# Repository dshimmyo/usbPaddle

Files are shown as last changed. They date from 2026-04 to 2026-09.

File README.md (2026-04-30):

I'm pretty nostalgic about old game consoles like the Atari 2600, and for years I've been wondering why I can't play games like Breakout or Kaboom! or Warlords with a proper paddle controller, so I set out to find out what I can do about it.
This project is the beginning of that adventure.
Basically, this is some arduino code that I installed into an Adafruit Keeboar 2040 which is based on and RP2040. Some time in the near future I'll build a more generic version using the RP2040.
Anyway, the gist of it is, you'll need a 10K potentiometer with ground on one outer lug and 3.3vdc on the other outer lug. The wiper is wired to one of the analog input pins on the kb2040.
The analog signal you get from the potentiometer is your paddle rotation. It's all in the code.
The reason this script is so huge is because I had to experiment with a bunch of modes to see what works where. But basically, just use the default mode.
Unfortunately it only works on basically on or two devices using one specific OS. I got it working on an Anbernic RG350xxH and RG40xxH running MuOS Banana.
For some reason, using that specific OS and whatever version of retroarch they use, it works great with the paddle. Every other software, OS compbination I've tried maps the paddle as if it's a joystick so it control velocity which is wrong.
The paddle is supposed to map directly to the position of the paddle.

Anyway, this would make more sense in a video and I'll post a schematic of my circuit soon.

Oh I forgot to mention I had to add a bunch of buttons to this paddle because when I switch to this device in retroarch I can't use the buttons on the anbernic so I needed a way to navigate out of the retroarch menus to play the game, thus all the dang buttons.



In this image I'm running a gametank game using the GameTankEmulator which has native support for my paddle because I programmed it that way ;)

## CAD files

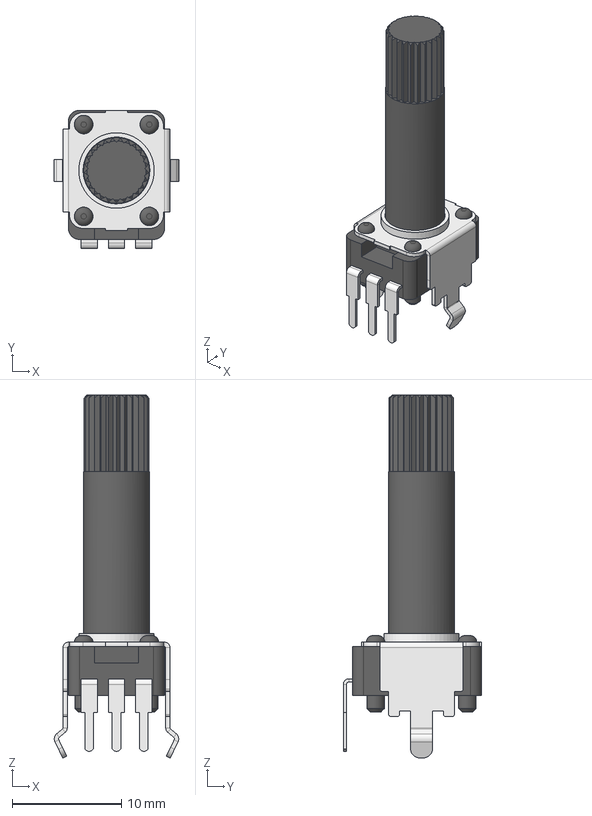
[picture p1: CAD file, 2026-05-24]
usbPaddleKicad/ALPS-RK09K_color.fcstd
11.4 x 12.6 x 33.2 mm
pin1
pin3
pin2

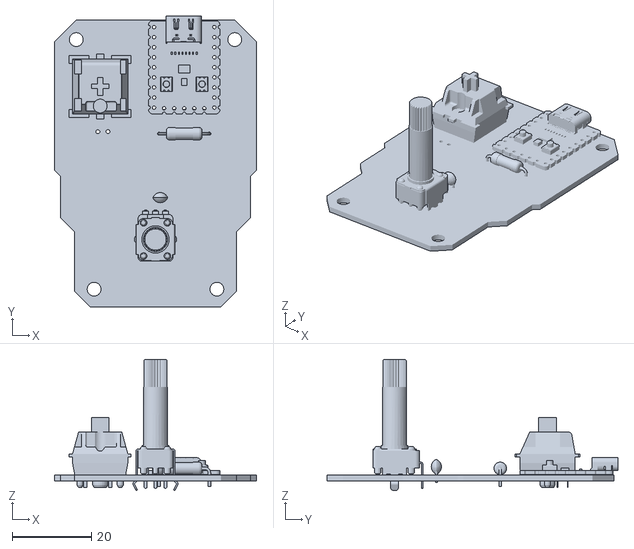
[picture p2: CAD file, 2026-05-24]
usbPaddleSingleKicad/paddleBaseStation.stl
51.0 x 73.4 x 33.2

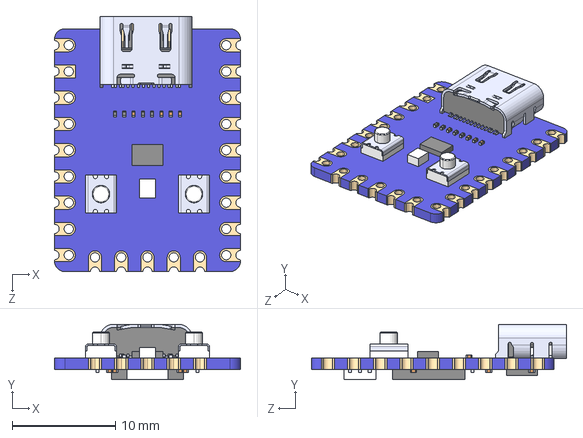
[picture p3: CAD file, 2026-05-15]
usbPaddleSingleKicad/RP2040-ZERO/RP2040-ZERO.step
18.0 x 5.35 x 24.7 mm

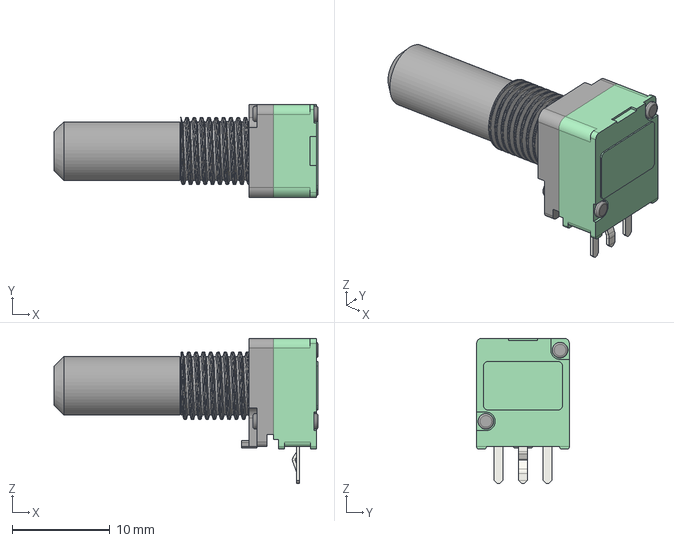
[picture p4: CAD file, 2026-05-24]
usbPaddleKicad/ALPS-RK097.step
27.1 x 9.50 x 14.9 mm

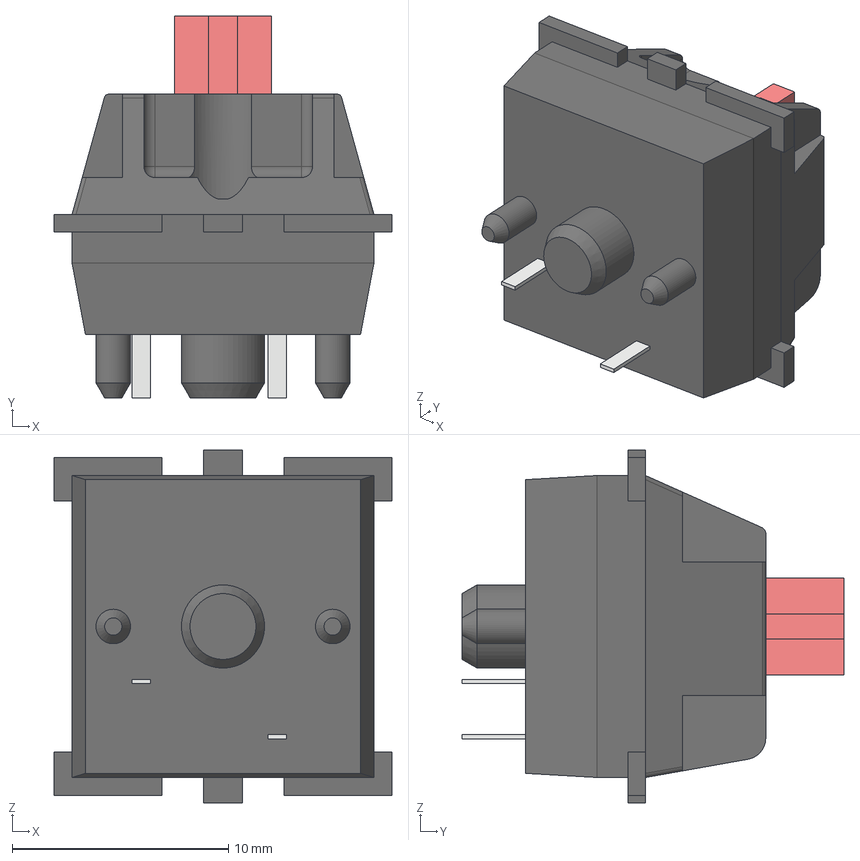
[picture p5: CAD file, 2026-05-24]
usbPaddleKicad/switch.step
15.6 x 17.7 x 16.3 mm

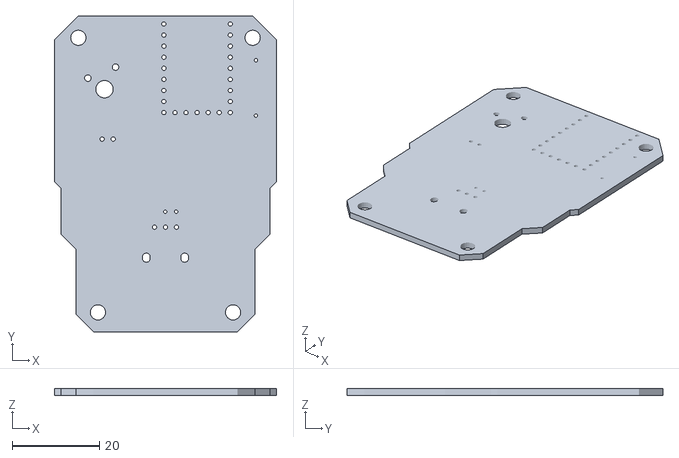
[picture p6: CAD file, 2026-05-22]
usbPaddleSingleKicad/paddleSingle.stl
51.0 x 72.5 x 1.51

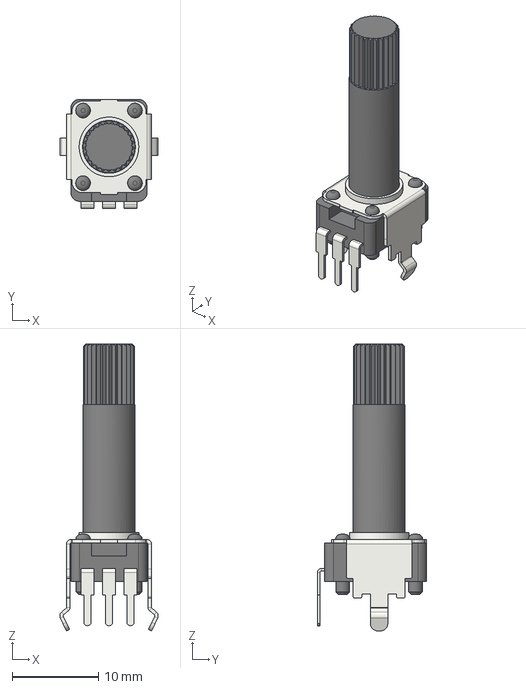
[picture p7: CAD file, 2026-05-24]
usbPaddleKicad/ALPS-RK09K.step
11.4 x 12.7 x 33.2 mm

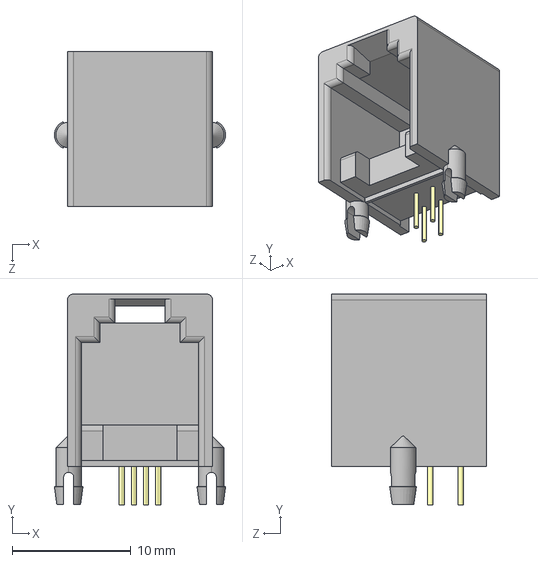
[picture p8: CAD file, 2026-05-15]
usbPaddleSingleKicad/GLX-N-64M--3DModel-STEP-484052.STEP
14.4 x 17.8 x 13.0 mm

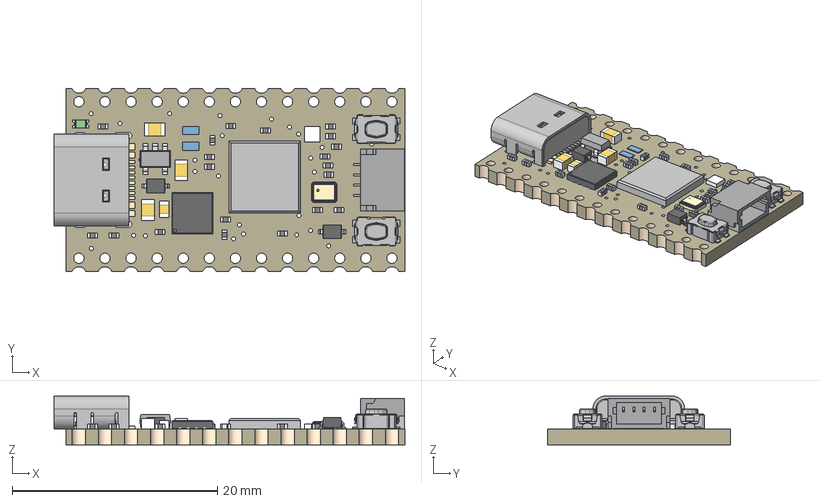
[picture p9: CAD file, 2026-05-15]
usbPaddleSingleKicad/5302 KB2040.step
34.2 x 17.8 x 4.77 mm
Board
10µF x 2
AP2112K-3.3
KMR2 x 2
10K x 20
WS2812B_SK6805_1515
NSR0320 x 2
8MB QSPI Flash
1uF x 2
RP2040_QFN56
12MHZ
1uF_1
USB TYPE C
FUSE
STEMMA_I2C_QTSKINNY
GREEN

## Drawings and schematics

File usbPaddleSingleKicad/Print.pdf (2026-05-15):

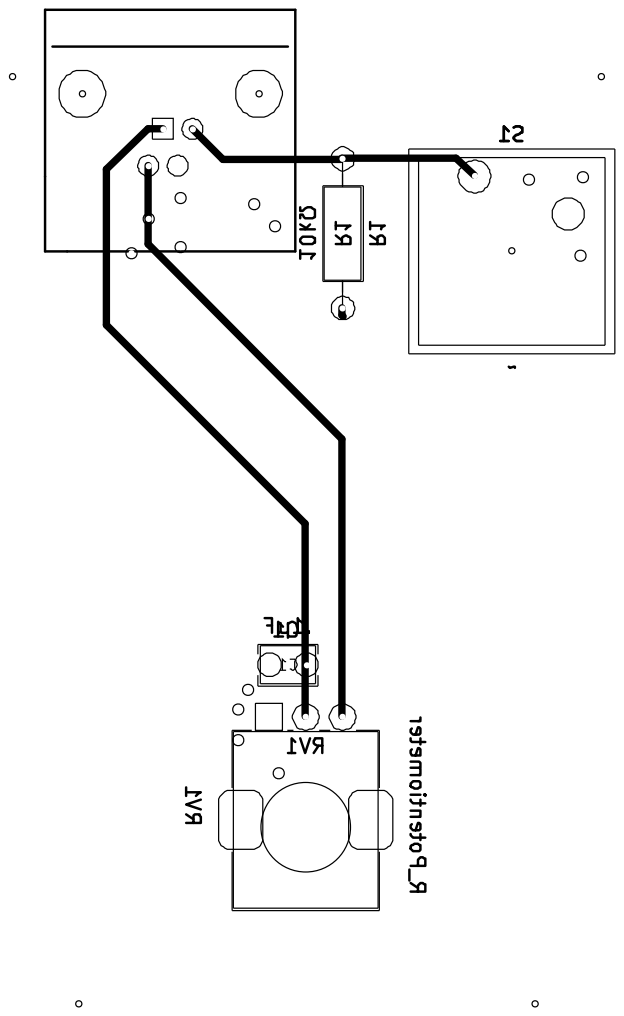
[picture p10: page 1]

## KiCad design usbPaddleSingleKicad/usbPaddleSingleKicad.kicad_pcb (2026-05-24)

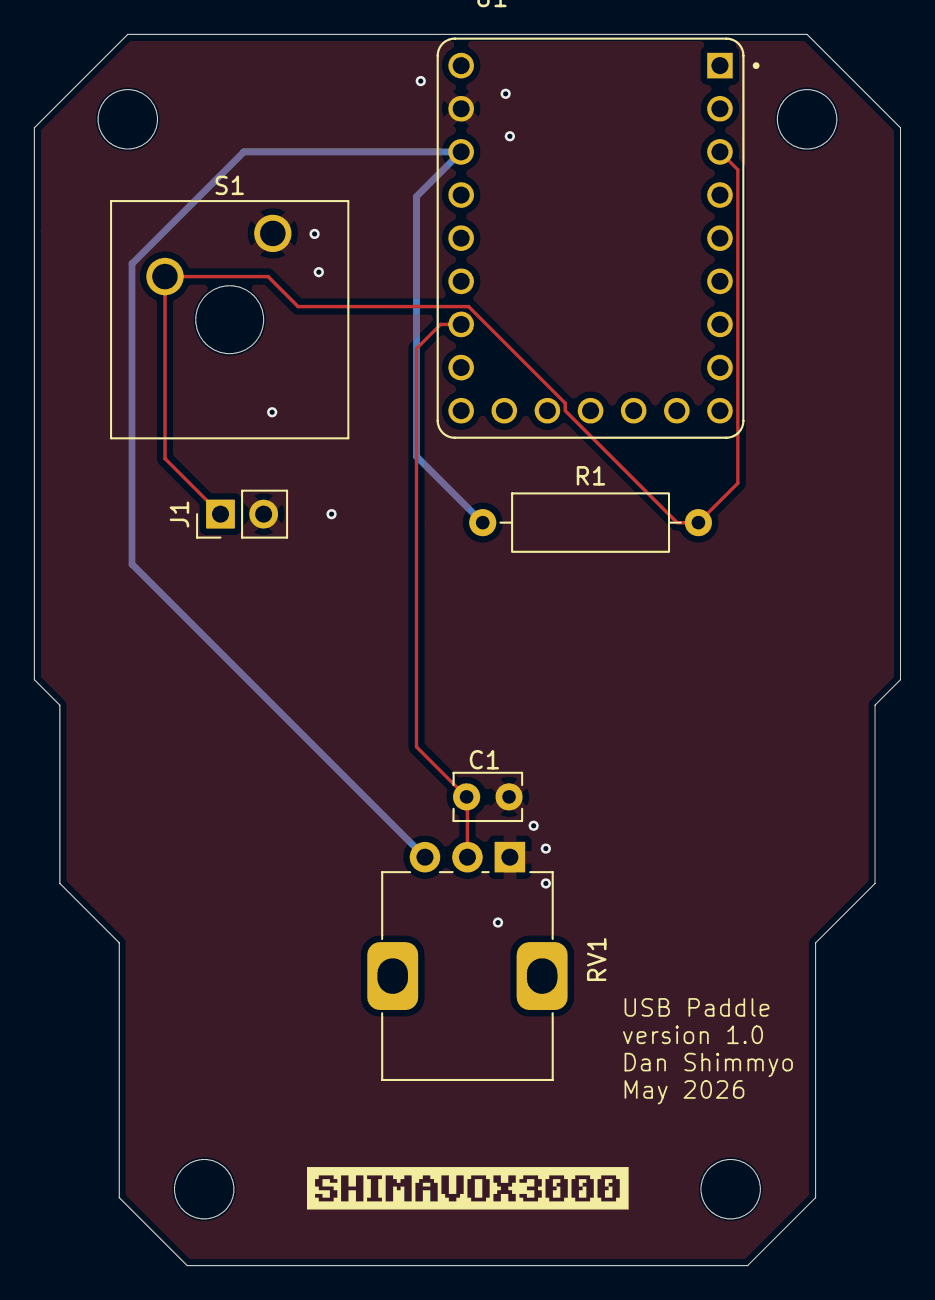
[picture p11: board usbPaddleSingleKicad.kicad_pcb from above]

Board: 2 copper layers, 51.0 x 72.5 mm, 6 parts (0 on the bottom side), 4 nets.

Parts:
C1: .1µF; C_Disc_D3.8mm_W2.6mm_P2.50mm
J1: Conn_01x02_Pin; PinHeader_1x02_P2.54mm_Vertical
R1: 10kΩ; R_Axial_DIN0309_L9.0mm_D3.2mm_P12.70mm_Horizontal
RV1: R_Potentiometer; Potentiometer_Alps_RK09K_Single_Vertical
S1: SW_Cherry_MX_1.00u_Plate
U1: RP2040-ZERO; MODULE_RP2040-ZERO

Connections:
GND: C1.1, J1.2, RV1.1, S1.1, U1.22 (GND)
unnamed: J1.1, R1.2, S1.2, U1.3 (GP2)
unnamed: C1.2, RV1.2, U1.17 (GP26)
VCC: R1.1, RV1.3, U1.21 (3V3)

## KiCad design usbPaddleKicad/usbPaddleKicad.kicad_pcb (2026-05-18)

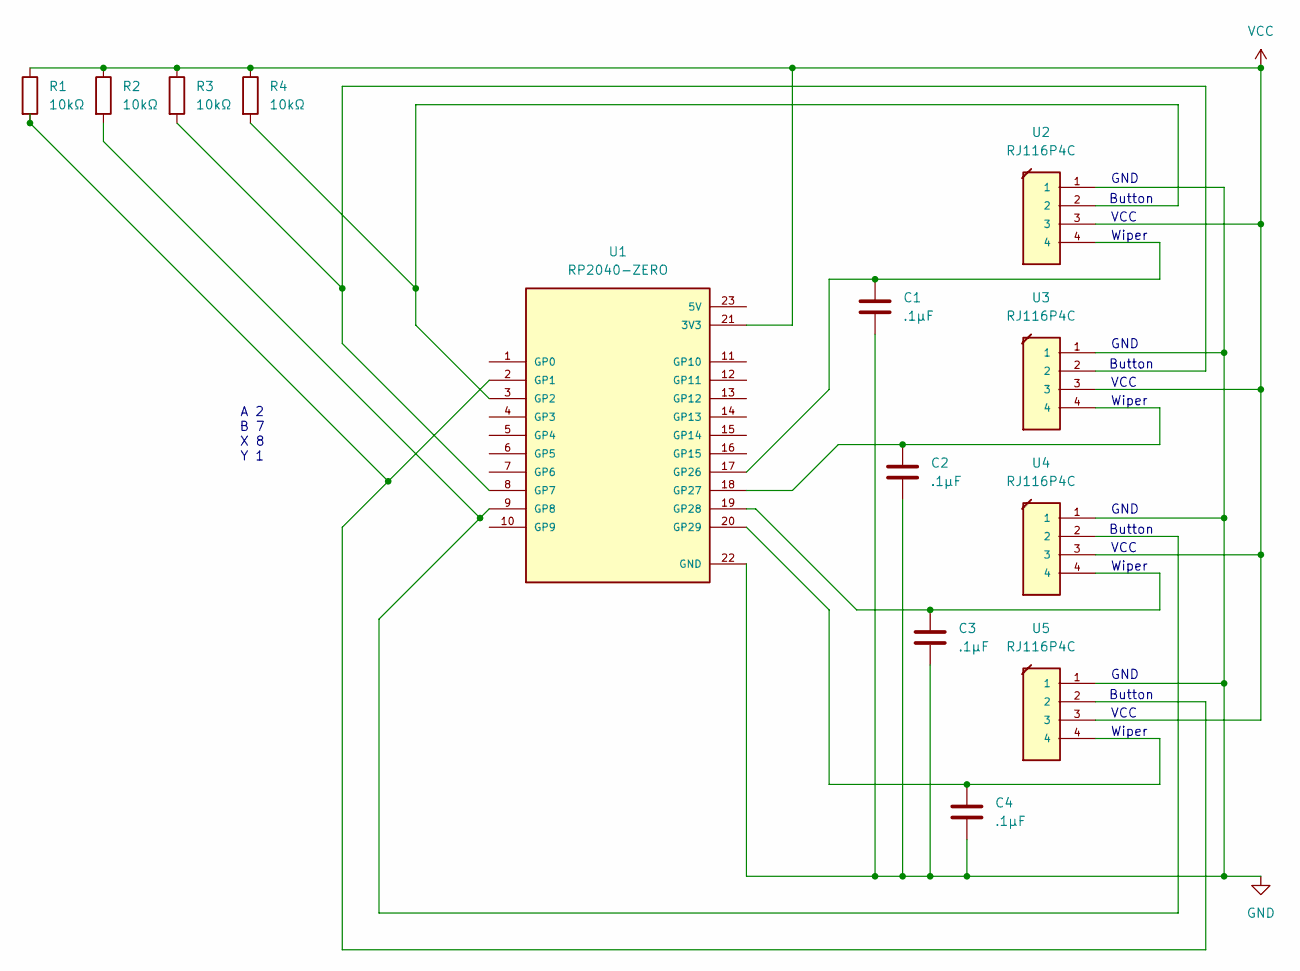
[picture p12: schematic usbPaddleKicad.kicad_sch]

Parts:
C1, C2, C3, C4: .1µF; C_Disc_D3.8mm_W2.6mm_P2.50mm
R1, R2, R3, R4: 10kΩ; R_Axial_DIN0309_L9.0mm_D3.2mm_P12.70mm_Horizontal
U1: RP2040-ZERO; MODULE_RP2040-ZERO; PARTREV NA
U2, U3, U4, U5: RJ116P4C; RJ6P4C_GLX-N-64M

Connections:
GND: C1.1, C2.1, C3.1, C4.1, U1.22 (GND), U2.1, U3.1, U4.1, U5.1
unnamed: R1.2, U1.2 (GP1), U5.2
unnamed: R4.2, U1.3 (GP2), U2.2
unnamed: R3.2, U1.8 (GP7), U3.2
unnamed: R2.2, U1.9 (GP8), U4.2
unnamed: C1.2, U1.17 (GP26), U2.4
unnamed: C2.2, U1.18 (GP27), U3.4
unnamed: C3.2, U1.19 (GP28), U4.4
unnamed: C4.2, U1.20 (GP29), U5.4
VCC: R1.1, R2.1, R3.1, R4.1, U1.21 (3V3), U2.3, U3.3, U4.3, U5.3

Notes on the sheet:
VCC
Wiper
GND
Button
A 2 B 7 X 8 Y 1

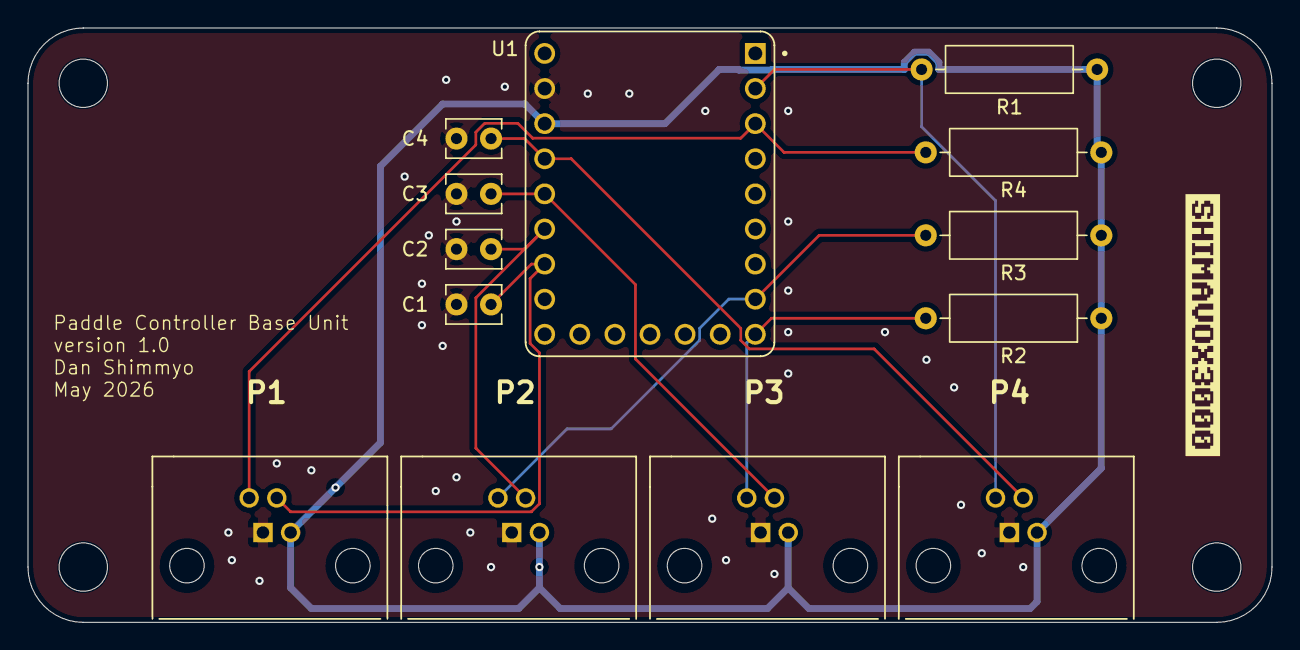
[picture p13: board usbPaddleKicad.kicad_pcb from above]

Board: 2 copper layers, 90.0 x 43.0 mm, 13 parts (0 on the bottom side), 10 nets.

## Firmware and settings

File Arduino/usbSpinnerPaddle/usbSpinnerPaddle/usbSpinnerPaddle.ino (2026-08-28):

#include "Adafruit_TinyUSB.h"
#include "hardware/watchdog.h" // Needed for RP2040 hardware reset

// -----------------------------------------------------------------------------
// USB HID Descriptors
// -----------------------------------------------------------------------------

// Standard HID Mouse Descriptor (No Report ID - Native Windows/Mac/Linux)
uint8_t const desc_mouse[] = {
  TUD_HID_REPORT_DESC_MOUSE()
};

// Standard HID Joystick Descriptor (Report ID 1)
uint8_t const desc_joystick[] = { 
  TUD_HID_REPORT_DESC_GAMEPAD(HID_REPORT_ID(1))
};

Adafruit_USBD_HID usb_hid;

// -----------------------------------------------------------------------------
// Pin Definitions
// -----------------------------------------------------------------------------
#define ENCODER_PIN_A   1//EC12 or EC16 Phase A (Flipped because of differing pinouts ABC instead of ACB)  // EC11 Phase A //0
#define ENCODER_PIN_B   0//EC12 or EC16 Phase B (Flipped because of differing pinouts ABC instead of ACB)  // EC11 Phase B //1
#define ACTION_BTN1     2  // Ext button gp2
#define ACTION_BTN2     3 // External Fire Button (GP3 to GND)

#define MODE_SWITCH_PIN 15 // Mode Toggle sampled ONCE at startup (and monitored for reboot)
#define TRIM_PIN 26        // Connect wiper to GP26 (A0)

#define MAX_TICKS_REFERENCE 600.0f
#define MIN_TICKS_REFERENCE 20.0f
#define ENCODER_TICKS_PER_ROTATION 24.0f//20.0f // (20.0f for EC11 24.0f for EC12 and EC16) //set this to the rotary encoder you are using in your build
#define SENSITIVITY_MULTIPLIER_MAX ((MAX_TICKS_REFERENCE / ENCODER_TICKS_PER_ROTATION) * 2.0f)
#define SENSITIVITY_MULTIPLIER_MIN (MIN_TICKS_REFERENCE / ENCODER_TICKS_PER_ROTATION)
#define PADDLE_SENSITIVITY_MULTIPLIER 0.83f// 300/360 reduced ticks due to the limited rotation

// -----------------------------------------------------------------------------
// Global Variables & State
// -----------------------------------------------------------------------------
volatile int32_t encoder_ticks = 0;
float virtual_paddle_pos = 0;
uint8_t last_encoder_state = 0;
bool is_paddle_mode = false; 
int last_mode_switch_state = HIGH; 

// 4-bit Quadrature Lookup Table
static const int8_t encoder_table[16] = {
     0,  1, -1,  0,
    -1,  0,  0,  1,
     1,  0,  0, -1,
     0, -1,  1,  0
};

// -----------------------------------------------------------------------------
// Interrupt Service Routine (ISR)
// -----------------------------------------------------------------------------
void readEncoderISR() {
  uint8_t a = digitalRead(ENCODER_PIN_A);
  uint8_t b = digitalRead(ENCODER_PIN_B);

  last_encoder_state = ((last_encoder_state << 2) | (a << 1) | b) & 0x0F;

  int8_t delta = encoder_table[last_encoder_state];
  if (delta != 0) {
    encoder_ticks += delta;
  }
}

// -----------------------------------------------------------------------------
// Setup
// -----------------------------------------------------------------------------
void setup() {
  pinMode(ENCODER_PIN_A, INPUT_PULLUP);
  pinMode(ENCODER_PIN_B, INPUT_PULLUP);
  pinMode(ACTION_BTN1, INPUT_PULLUP);
  pinMode(MODE_SWITCH_PIN, INPUT_PULLUP);
  pinMode(ACTION_BTN2, INPUT_PULLUP);
  analogReadResolution(12); // RP2040 12-bit ADC
  delay(50); 

  last_mode_switch_state = digitalRead(MODE_SWITCH_PIN);
  is_paddle_mode = (last_mode_switch_state == LOW);

  last_encoder_state = (digitalRead(ENCODER_PIN_A) << 1) | digitalRead(ENCODER_PIN_B);

  attachInterrupt(digitalPinToInterrupt(ENCODER_PIN_A), readEncoderISR, CHANGE);
  attachInterrupt(digitalPinToInterrupt(ENCODER_PIN_B), readEncoderISR, CHANGE);

  TinyUSBDevice.setManufacturerDescriptor("Open-Source");

  if (is_paddle_mode) {
    TinyUSBDevice.setID(0x239A, 0x8110);
    TinyUSBDevice.setProductDescriptor("Virtual Paddle Controller");
    usb_hid.setPollInterval(2);
    usb_hid.setReportDescriptor(desc_joystick, sizeof(desc_joystick));
    usb_hid.begin();
  } else {
    TinyUSBDevice.setID(0x239A, 0x8111);
    TinyUSBDevice.setProductDescriptor("Spinner Controller");
    usb_hid.setPollInterval(2);
    usb_hid.setBootProtocol(HID_ITF_PROTOCOL_MOUSE);
    usb_hid.setReportDescriptor(desc_mouse, sizeof(desc_mouse));
    usb_hid.begin();
  }
}

// -----------------------------------------------------------------------------
// Main Loop
// -----------------------------------------------------------------------------
void loop() {
  int current_switch_state = digitalRead(MODE_SWITCH_PIN);
  if (current_switch_state != last_mode_switch_state) {
    delay(20); 
    if (digitalRead(MODE_SWITCH_PIN) == current_switch_state) {
      watchdog_reboot(0, 0, 0); 
    }
  }

  if (!usb_hid.ready()) return;

  int raw_trim = analogRead(TRIM_PIN);
  float pMult = is_paddle_mode ? PADDLE_SENSITIVITY_MULTIPLIER : 1.0f;
  float max_mult = SENSITIVITY_MULTIPLIER_MAX * pMult;
  float min_mult = SENSITIVITY_MULTIPLIER_MIN;

  float norm_trim = raw_trim / 4095.0f;
  float sensitivity = min_mult * powf(max_mult / min_mult, norm_trim);

  noInterrupts();
  int32_t ticks = encoder_ticks;
  encoder_ticks = 0;
  interrupts();

  bool fire1_pressed = (digitalRead(ACTION_BTN1) == LOW);
  bool fire2_pressed = (digitalRead(ACTION_BTN2) == LOW);

  if (is_paddle_mode) {
    if (ticks != 0) {
      virtual_paddle_pos += ((float)ticks * sensitivity);
      if (virtual_paddle_pos > 127.0f)  virtual_paddle_pos = 127.0f;
      if (virtual_paddle_pos < -127.0f) virtual_paddle_pos = -127.0f;
    }

    uint32_t buttons = 0;
    if (fire1_pressed) buttons |= (1 << 0); // Button 1
    if (fire2_pressed) buttons |= (1 << 1); // Button 2

    hid_gamepad_report_t report = {
      .x       = (int8_t)virtual_paddle_pos,
      .y       = 0,
      .z       = 0,
      .rz      = 0,
      .rx      = 0,
      .ry      = 0,
      .hat     = 0,
      .buttons = buttons
    };

    usb_hid.sendReport(1, &report, sizeof(report));

  } else {
    static float mouse_x_accumulator = 0.0f;

    mouse_x_accumulator += ((float)ticks * sensitivity);
    int8_t mouse_dx = (int8_t)mouse_x_accumulator;
    mouse_x_accumulator -= (float)mouse_dx;

    mouse_dx = (int8_t)constrain(mouse_dx, -127, 127);

    uint8_t buttons = 0;
    if (fire1_pressed) buttons |= MOUSE_BUTTON_LEFT;
    if (fire2_pressed) buttons |= MOUSE_BUTTON_MIDDLE;

    usb_hid.mouseReport(0, buttons, mouse_dx, 0, 0, 0);
  }
}

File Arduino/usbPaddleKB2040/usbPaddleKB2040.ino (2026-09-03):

#include "Adafruit_TinyUSB.h"
#include <Adafruit_NeoPixel.h>

uint8_t const desc_normal[] = { 
  // Collection 1: Standard Joystick Baseline
  0x05, 0x01,        // Usage Page (Generic Desktop)
  0x09, 0x04,        // Usage (Joystick) - Changed from 0x05
  0xa1, 0x01,        // Collection (Application)
    0x85, 0x01,      //   REPORT ID (1) - MUST BE EXPLICIT
    0x09, 0x01,      //   Usage (Pointer)
    0xa1, 0x00,      //   Collection (Physical)
      0x05, 0x01,    //     Usage Page (Generic Desktop)
      0x09, 0x30,    //     Usage (X)
      0x09, 0x31,    //     Usage (Y)
      0x09, 0x32,    //     Usage (Z)
      0x09, 0x33,    //     Usage (Rx)  <-- Changed from 0x35
      0x15, 0x81,    //     Logical Minimum (-127)
      0x25, 0x7f,    //     Logical Maximum (127)
      0x75, 0x08,    //     Report Size (8 bits)
      0x95, 0x04,    //     Report Count (4)
      0x81, 0x02,    //     Input (Data, Var, Abs)
    0xc0,            //   End Physical Collection
    0x05, 0x09,      //   Usage Page (Button)
    0x19, 0x01,      //   Usage Minimum (1)
    0x29, 0x20,      //   Usage Maximum (32)
    0x15, 0x00,      //   Logical Minimum (0)
    0x25, 0x01,      //   Logical Maximum (1)
    0x75, 0x01,      //   Report Size (1 bit)
    0x95, 0x20,      //   Report Count (32)
    0x81, 0x02,      //   Input (Data, Var, Abs)
    0x05, 0x01,      //   Usage Page (Generic Desktop)
    0x09, 0x39,      //   Usage (Hat Switch)
    0x15, 0x00,      //   Logical Minimum (0)
    0x25, 0x07,      //   Logical Maximum (7)
    0x35, 0x00,      //   Physical Minimum (0)
    0x46, 0x3b, 0x01,//   Physical Maximum (315)
    0x65, 0x14,      //   Unit (20)
    0x75, 0x04,      //   Report Size (4 bits)
    0x95, 0x01,      //   Report Count (1)
    0x81, 0x42,      //   Input (Data, Var, Abs)
    0x75, 0x04,      //   Report Size (4 bits) - Padding
    0x95, 0x01,      //   Report Count (1)
    0x81, 0x01,      //   Input (Const)
  0xc0,              // End Collection (Application)

};

Adafruit_USBD_HID usb_hid;

// Define Pins
#define NEOPIXEL_PIN 16
#define NUM_PIXELS   1

#define POT_PIN1 26 //A0
#define POT_PIN2 27 //A1
#define POT_PIN3 28 //A2
#define POT_PIN4 29 //A3
#define BTN_UP 3
#define BTN_DOWN 4
#define BTN_LEFT 5
#define BTN_RIGHT 6
#define BTN_A 2 //down//7 (right)
#define BTN_B 7 //right//8 (left)
#define BTN_SELECT 9
#define BTN_START 10// underside of RP2040
#define BTN_L1 11
#define BTN_R1 12
#define BTN_L2 13
#define BTN_R2 14

#define BTN_MENU 0 
#define BTN_X 8//left //up 1
#define BTN_Y 1//up //down 2

#define PADDLE_DPAD_HAT_UP        0
#define PADDLE_DPAD_HAT_RIGHT     2
#define PADDLE_DPAD_HAT_DOWN      4
#define PADDLE_DPAD_HAT_LEFT      6
#define PADDLE_DPAD_HAT_CENTERED  8

typedef struct TU_ATTR_PACKED {
  int8_t  p1;         // Paddle 1 (X)
  int8_t  p2;         // Paddle 2 (Y)
  int8_t  p3;         // Paddle 3 (Z)
  int8_t  p4;         // Paddle 4 (Rz)
  uint32_t buttons;
  uint8_t hat_byte;
} dks_report_t;

Adafruit_NeoPixel statusLed(NUM_PIXELS, NEOPIXEL_PIN, NEO_GRB + NEO_KHZ800);

void setup() {
  statusLed.begin();
    
  // Set a very faint amber glow (Red = 2, Green = 1, Blue = 0)
  statusLed.setPixelColor(0, statusLed.Color(2, 1, 0));
  statusLed.show();

  pinMode(BTN_UP, INPUT_PULLUP);
  pinMode(BTN_DOWN, INPUT_PULLUP);
  pinMode(BTN_LEFT, INPUT_PULLUP);
  pinMode(BTN_RIGHT, INPUT_PULLUP);
  pinMode(BTN_A, INPUT_PULLUP);
  pinMode(BTN_B, INPUT_PULLUP);
  pinMode(BTN_SELECT, INPUT_PULLUP);
  pinMode(BTN_START, INPUT_PULLUP);
  pinMode(BTN_MENU, INPUT_PULLUP);
  pinMode(BTN_X, INPUT_PULLUP);
  pinMode(BTN_Y, INPUT_PULLUP);
  pinMode(BTN_L1, INPUT_PULLUP);
  pinMode(BTN_R1, INPUT_PULLUP);
  pinMode(BTN_L2, INPUT_PULLUP);
  pinMode(BTN_R2, INPUT_PULLUP);
  pinMode(POT_PIN1, INPUT_PULLDOWN); // (ADC)
  pinMode(POT_PIN2, INPUT_PULLDOWN); // (ADC)
  pinMode(POT_PIN3, INPUT_PULLDOWN); // (ADC)
  pinMode(POT_PIN4, INPUT_PULLDOWN); // (ADC)

  delay(50); // Debounce

  TinyUSBDevice.setID(0x239A, 0x8108);
  usb_hid.setReportDescriptor(desc_normal, sizeof(desc_normal));
  
  TinyUSBDevice.setManufacturerDescriptor("Open-Source");
  TinyUSBDevice.setProductDescriptor("Paddle Controller");

  usb_hid.setPollInterval(2);
  usb_hid.begin();
  analogReadResolution(12);
}

void loop() {
  if (!usb_hid.ready()) return;

  // Paddle1
  int rawValue1 = analogRead(POT_PIN1);
  int8_t p1_axis = map(rawValue1, 0, 4095, -127, 127);
  if (rawValue1 < 5) { //needs a pulldown
      p1_axis = 0; //center when disconnected
  }
  // Paddle2
  int rawValue2 = analogRead(POT_PIN2);
  int8_t p2_axis = map(rawValue2, 0, 4095, -127, 127);
  if (rawValue2 < 5) { //needs a pulldown
      p2_axis = 0; //center when disconnected
  }
  // Paddle3
  int rawValue3 = analogRead(POT_PIN3);
  int8_t p3_axis = map(rawValue3, 0, 4095, -127, 127);
  if (rawValue3 < 5) { //needs a pulldown
      p3_axis = 0; //center when disconnected
  }
  // Paddle4
  int rawValue4 = analogRead(POT_PIN4);
  int8_t p4_axis = map(rawValue4, 0, 4095, -127, 127);
  if (rawValue4 < 5) { //needs a pulldown
      p4_axis = 0; //center when disconnected
  }

  // 2. D-Pad (The Hat)
  uint8_t hat = PADDLE_DPAD_HAT_CENTERED;
  if      (!digitalRead(BTN_UP))    hat = PADDLE_DPAD_HAT_UP;
  else if (!digitalRead(BTN_DOWN))  hat = PADDLE_DPAD_HAT_DOWN;
  else if (!digitalRead(BTN_LEFT))  hat = PADDLE_DPAD_HAT_LEFT;
  else if (!digitalRead(BTN_RIGHT)) hat = PADDLE_DPAD_HAT_RIGHT;

  // 3. Standard Xbox/XInput Mapping
  uint32_t buttons = 0;
  
  if (!digitalRead(BTN_A))      buttons |= (1 << 0);  // A (Bottom)
  if (!digitalRead(BTN_B))      buttons |= (1 << 1);  // B (Right)
  if (!digitalRead(BTN_X))      buttons |= (1 << 2);  // X (Left)
  if (!digitalRead(BTN_Y))      buttons |= (1 << 3);  // Y (Top)
  if (!digitalRead(BTN_L1))     buttons |= (1 << 4);  // Left Bumper
  if (!digitalRead(BTN_R1))     buttons |= (1 << 5);  // Right Bumper
  if (!digitalRead(BTN_SELECT)) buttons |= (1 << 6);  // Select/Back
  if (!digitalRead(BTN_START))  buttons |= (1 << 7);  // Start
  if (!digitalRead(BTN_L2))     buttons |= (1 << 8);  // Left Trigger
  if (!digitalRead(BTN_R2))     buttons |= (1 << 9);  // Right Trigger
  if (!digitalRead(BTN_MENU))   buttons |= (1 << 10); // Guide/Menu
  
  dks_report_t report;
  memset(&report, 0, sizeof(report));
  report.p1       = p1_axis;
  report.p2       = p2_axis;
  report.p3       = p3_axis;
  report.p4       = p4_axis;
  report.buttons = buttons;
  report.hat_byte = hat;
  usb_hid.sendReport(1, &report, sizeof(report));

  //delay(10);
}

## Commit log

2026-04-20 adding 3 new buttons and flip/flop a and b buttons
    [usbPaddleKB2040.ino]
2026-04-21 pin assignments for 4 paddle hub
2026-04-28 add mouse mode for steamdeck (doesn't work)
    [usbPaddleKB2040.ino]
2026-05-04 adds internal pull-down to adc pins attempt to center pot when disconnected but it doesn't work. The circuit probably need a pull-down resistor
    [usbPaddleKB2040.ino]
2026-05-04 changed orientation of face buttons to match xbox standard, easier to do it here rather than on my prototype
2026-05-04 rearranged face button pins to match my hacky perfboard physical layout
2026-05-04 switch to x-box standard button profile for maximum compatibility
2026-05-04 fill out unused buttons for max compatibility
2026-05-15 add kicad project
    [5302 KB2040.step, RP2040-ZERO.step, usbPaddleKicad.kicad_pcb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]
2026-05-15 wired 4 jacks to rp2040 in schematic
    [usbPaddleKicad.kicad_sch]
2026-05-15 added filter caps and pull-up resistors
    [usbPaddleKicad.kicad_sch]
2026-05-15 pcb layout first pass, not fully routed
    [GLX-N-64M--3DModel-STEP-484052.STEP, usbPaddleKicad.kicad_pcb, usbPaddleKicad.kicad_sch]
2026-05-15 clean up pcb edges and corners
    [usbPaddleKicad.kicad_pcb]
2026-05-15 add silkscreens
    [usbPaddleKicad.kicad_pcb]
2026-05-16 added port numbers
    [usbPaddleKicad.kicad_pcb]
2026-05-16 port numbering in back silkscreen
    [usbPaddleKicad.kicad_pcb]
2026-05-17 final gerbers
    [usbPaddleKicad-B_Cu.gbl, usbPaddleKicad-B_Mask.gbs, usbPaddleKicad-B_Silkscreen.gbo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]
2026-05-18 update RJ11 port footprints from library
    [usbPaddleKicad.kicad_pcb]
2026-05-22 add new project for usb single paddle basic schematic done
    [5302 KB2040.step, GLX-N-64M--3DModel-STEP-484052.STEP, RP2040-ZERO.step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]
2026-05-22 new single paddle pcb
    [paddleSingle.stl, usbPaddleSingleKicad.kicad_pcb, usbPaddleSingleKicad.kicad_sch]
2026-05-23 adjust layout
    [usbPaddleSingleKicad.kicad_pcb]
2026-05-23 single paddle gerbers
    [usbPaddleSingleKicad-B_Cu.gbl, usbPaddleSingleKicad-B_Mask.gbs, usbPaddleSingleKicad-B_Silkscreen.gbo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]
2026-05-24 add step and stl models
    [ALPS-RK097.step, ALPS-RK09K.step, ALPS-RK09K_color.fcstd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]
2026-08-11 first pass, 20-tick rotary encoder works but paddle mode does nothing
2026-08-11 second attempt for combo functionality, still not working as a paddle
    [usbSpinnerPaddle.ino]
2026-08-11 working combo spinner/paddle that detects switched state only at startup
2026-08-12 start kicad schematic
    [usbSpinnerPaddleKicad.kicad_pcb, usbSpinnerPaddleKicad.kicad_sch]
2026-08-12 refactor(encoder): switch ISR to 4-bit state machine lookup table
    Replace manual if/else state checking in readEncoderISR() with a 4-bit
    lookup table ([Old_A, Old_B, New_A, New_B]) to handle quadrature state
    transitions and filter invalid wiper bounce states.
    [usbSpinnerPaddle.ino]
2026-08-12 added support for a second button so I can play tempest properly
2026-08-13 more detailed sensitivity switching
2026-08-13 auto reboot after toggle
    [usbSpinnerPaddle.ino]
2026-08-14 schematic update
    [usbSpinnerPaddleKicad.kicad_sch]
2026-08-17 spinner edits for clarity
    [usbSpinnerPaddleKicad.kicad_sch]
2026-08-28 fixes for windows machines
    [usbSpinnerPaddle.ino]
2026-09-03 dim neopixel to indicate power on
